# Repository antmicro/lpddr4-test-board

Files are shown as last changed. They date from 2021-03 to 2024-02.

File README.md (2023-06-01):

# LPDDR4 test board

Copyright (c) 2021-2023 [Antmicro](https://antmicro.com)



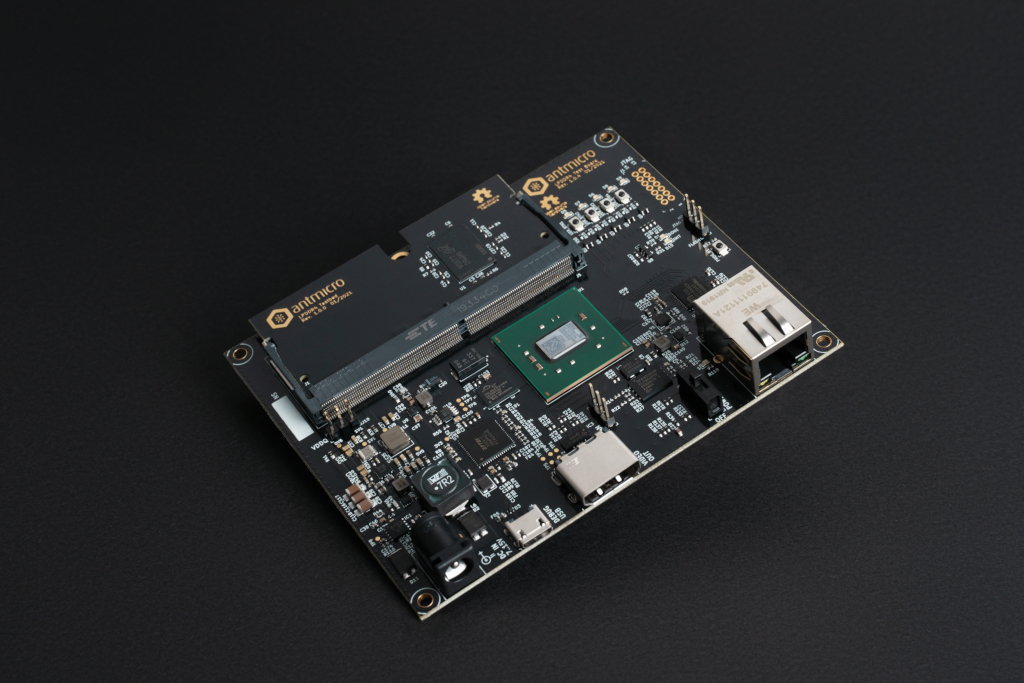
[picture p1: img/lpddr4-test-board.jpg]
LPDDR4 test board


## Overview

This repository contains open hardware design files for an experimental platform built around Xilinx Kintex-7 FPGA.
The main purpose of this platform is to develop and customize RAM controllers supporting LPDDR4 ICs.

This hardware platform is supported by the [Rowhammer Tester](https://github.com/antmicro/rowhammer-tester) gateware.
It can be used to investigate Rowhammer DRAM attacks.
You can learn more about Rowhammer attacks from this blog [note](https://antmicro.com/blog/2021/08/open-source-ddr-test-framework-for-rowhammer/).
The usage instructions for this board are also provided in the [Row Hammer Tester documentation](https://rowhammer-tester.readthedocs.io/en/latest/).

The design files for this board were prepared in KiCad.

## Repository structure

The main repository directory contains KiCad PCB project files, a LICENSE and README.
The remaining files are stored in the following directories:

* `lib` - contains the component libraries
* `img` - contains graphics for this README

## Key features

* Kintex-7 FPGA - XC7K70T-FBG484
* Modular design with custom DDR4 SO-DIMM connector for various testbeds
* HDMI output connector
* Ethernet RJ45 connector with 1GbE transceiver
* Micro USB debug connector with FT4232HQ FTDI USB controller
* JTAG
* microSD card slot
* 16Mbytes S25FL128S QSPI FLASH memory
* S27KL0641 HyperRAM
* External 7-12V power input
* 5 user LEDs
* 4 user buttons

The LPDDR4 test board is electrically compatible with the following testbeds:

* [LPDDR4 Testbed](https://github.com/antmicro/lpddr4-testbed) with a single LPDDR4 IC
* [DDR5 Testbed](https://github.com/antmicro/ddr5-testbed) with a signle DDR5 IC

## Block diagram

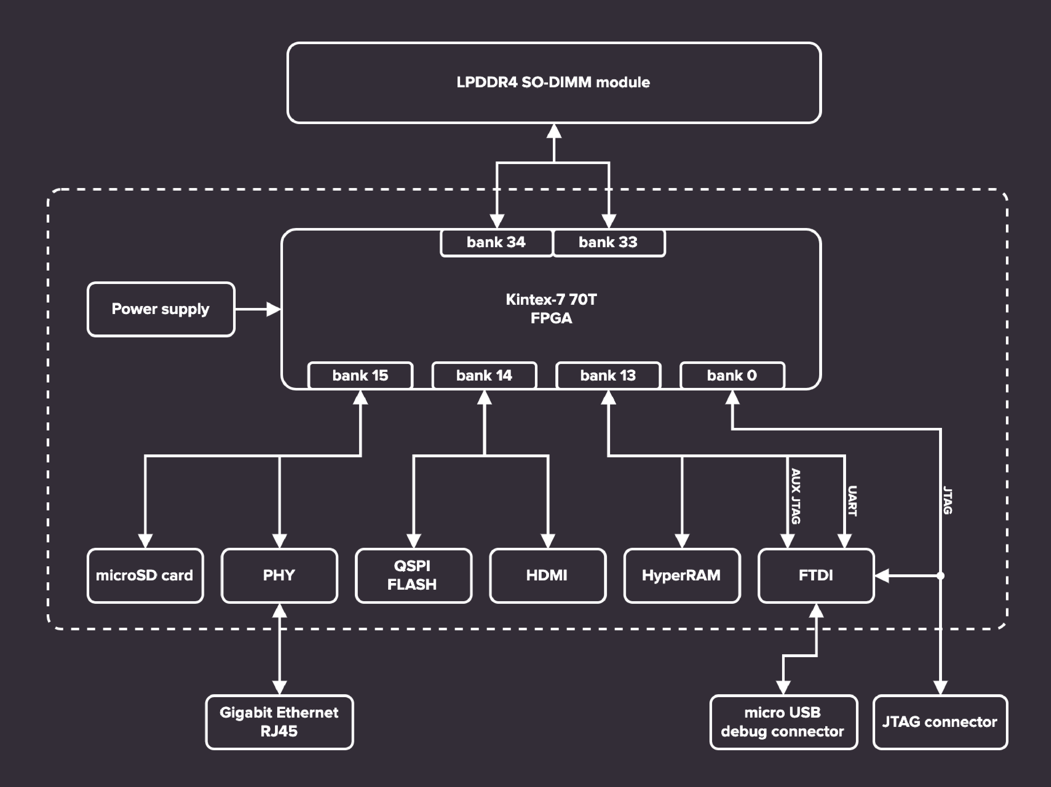
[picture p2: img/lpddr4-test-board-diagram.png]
Block diagram


## Licensing

This project is published under the [Apache-2.0](LICENSE) license.

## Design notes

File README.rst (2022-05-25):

=================
LPDDR4 test board
=================

Copyright (c) 2020-2022 `Antmicro <https://www.antmicro.com>`_





Overview
--------

This repository contains open hardware design files for an experimental platform built around Xilinx Kintex-7 FPGA.
The main purpose of this platform is to develop and customize RAM controllers supporting LPDDR4 ICs.

This hardware platform is supported by the `LiteX Rowhammer Tester <https://github.com/antmicro/litex-rowhammer-tester>`_ gateware. It can be used to investigate Rowhammer DRAM attacks. You can learn more about Rowhammer attacks from this blog `note <https://antmicro.com/blog/2021/08/open-source-ddr-test-framework-for-rowhammer/>`_.
The usage instructions for this board are also provided in the `LiteX Row Hammer Tester documentation <https://litex-rowhammer-tester.readthedocs.io/en/latest/>`_. 

The design files for this board were prepared in KiCad.

Repository structure
--------------------
The main repository directory contains KiCad PCB project files, a LICENSE and README.
The remaining files are stored in the following directories:

* ``lib`` - contains the component libraries
* ``img`` - contains graphics for this README

Key features
------------

* Kintex-7 FPGA - XC7K70T-FBG484
* Modular design with custom DDR4 SO-DIMM connector
* HDMI output connector
* Ethernet RJ45 connector with 1GbE transceiver
* Micro USB debug connector with FT4232HQ FTDI USB controller
* JTAG
* microSD card slot
* 16Mbytes S25FL128S QSPI FLASH memory
* S27KL0641 HyperRAM
* External 7-12V power input
* 5 user LEDs
* 4 user buttons

Block diagram
-------------


	
License
=======

`Apache-2.0 <LICENSE>`_

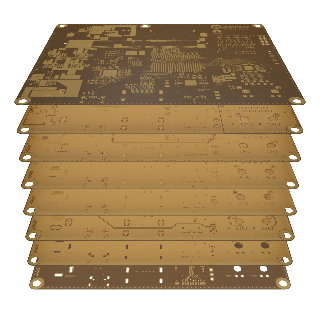
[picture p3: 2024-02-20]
assets/previews/layer1_thumbnail.webp

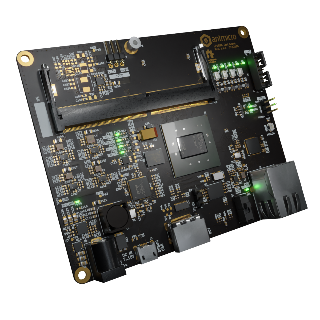
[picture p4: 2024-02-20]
assets/previews/leftT_thumbnail.png

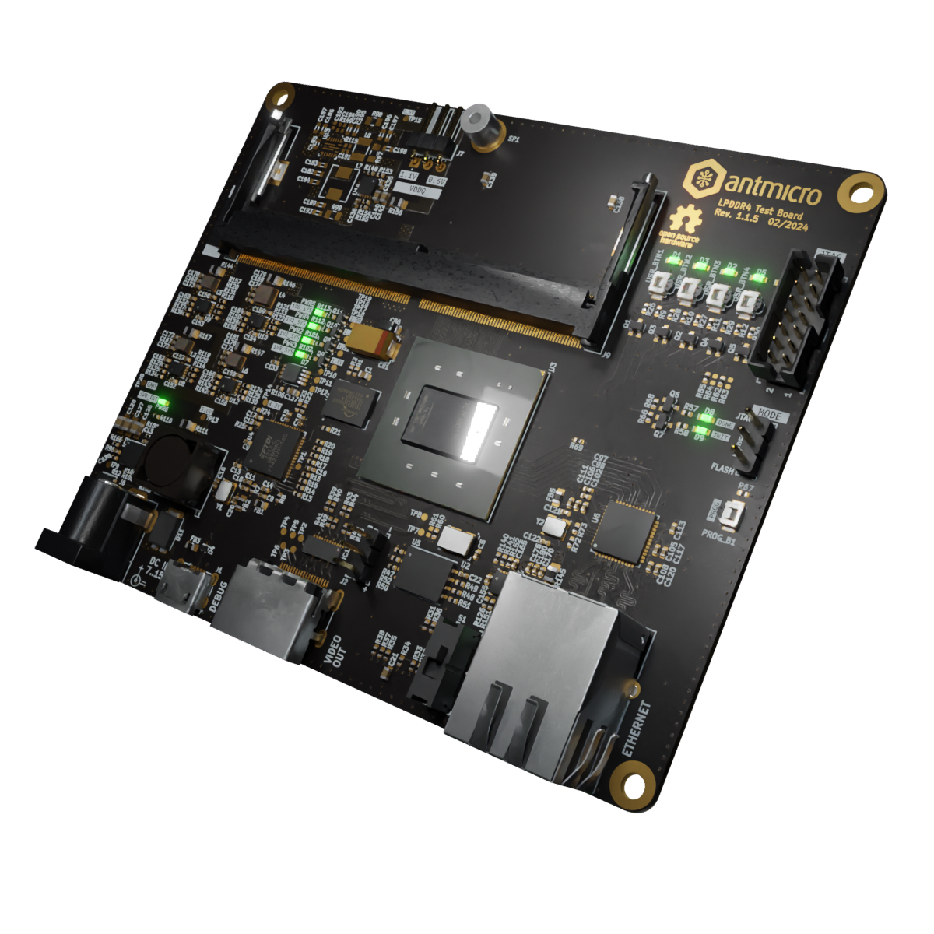
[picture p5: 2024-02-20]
assets/previews/rightT.webp

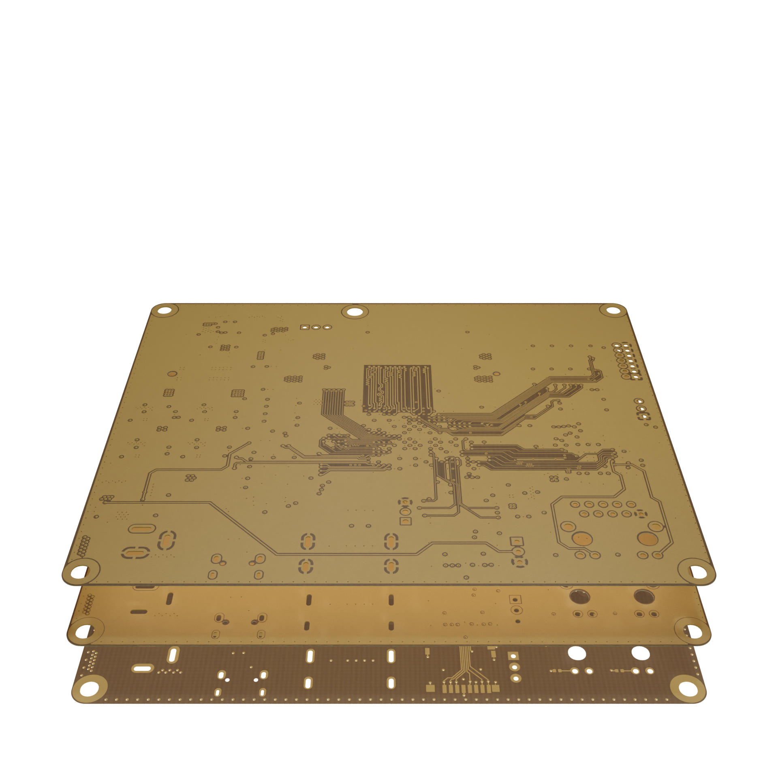
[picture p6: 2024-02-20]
assets/previews/layer6.png

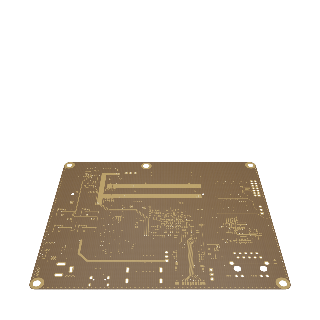
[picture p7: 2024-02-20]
assets/previews/layer8_thumbnail.png

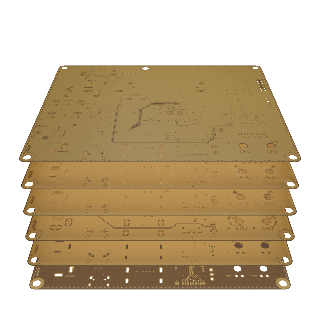
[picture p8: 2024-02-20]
assets/previews/layer3_thumbnail.webp

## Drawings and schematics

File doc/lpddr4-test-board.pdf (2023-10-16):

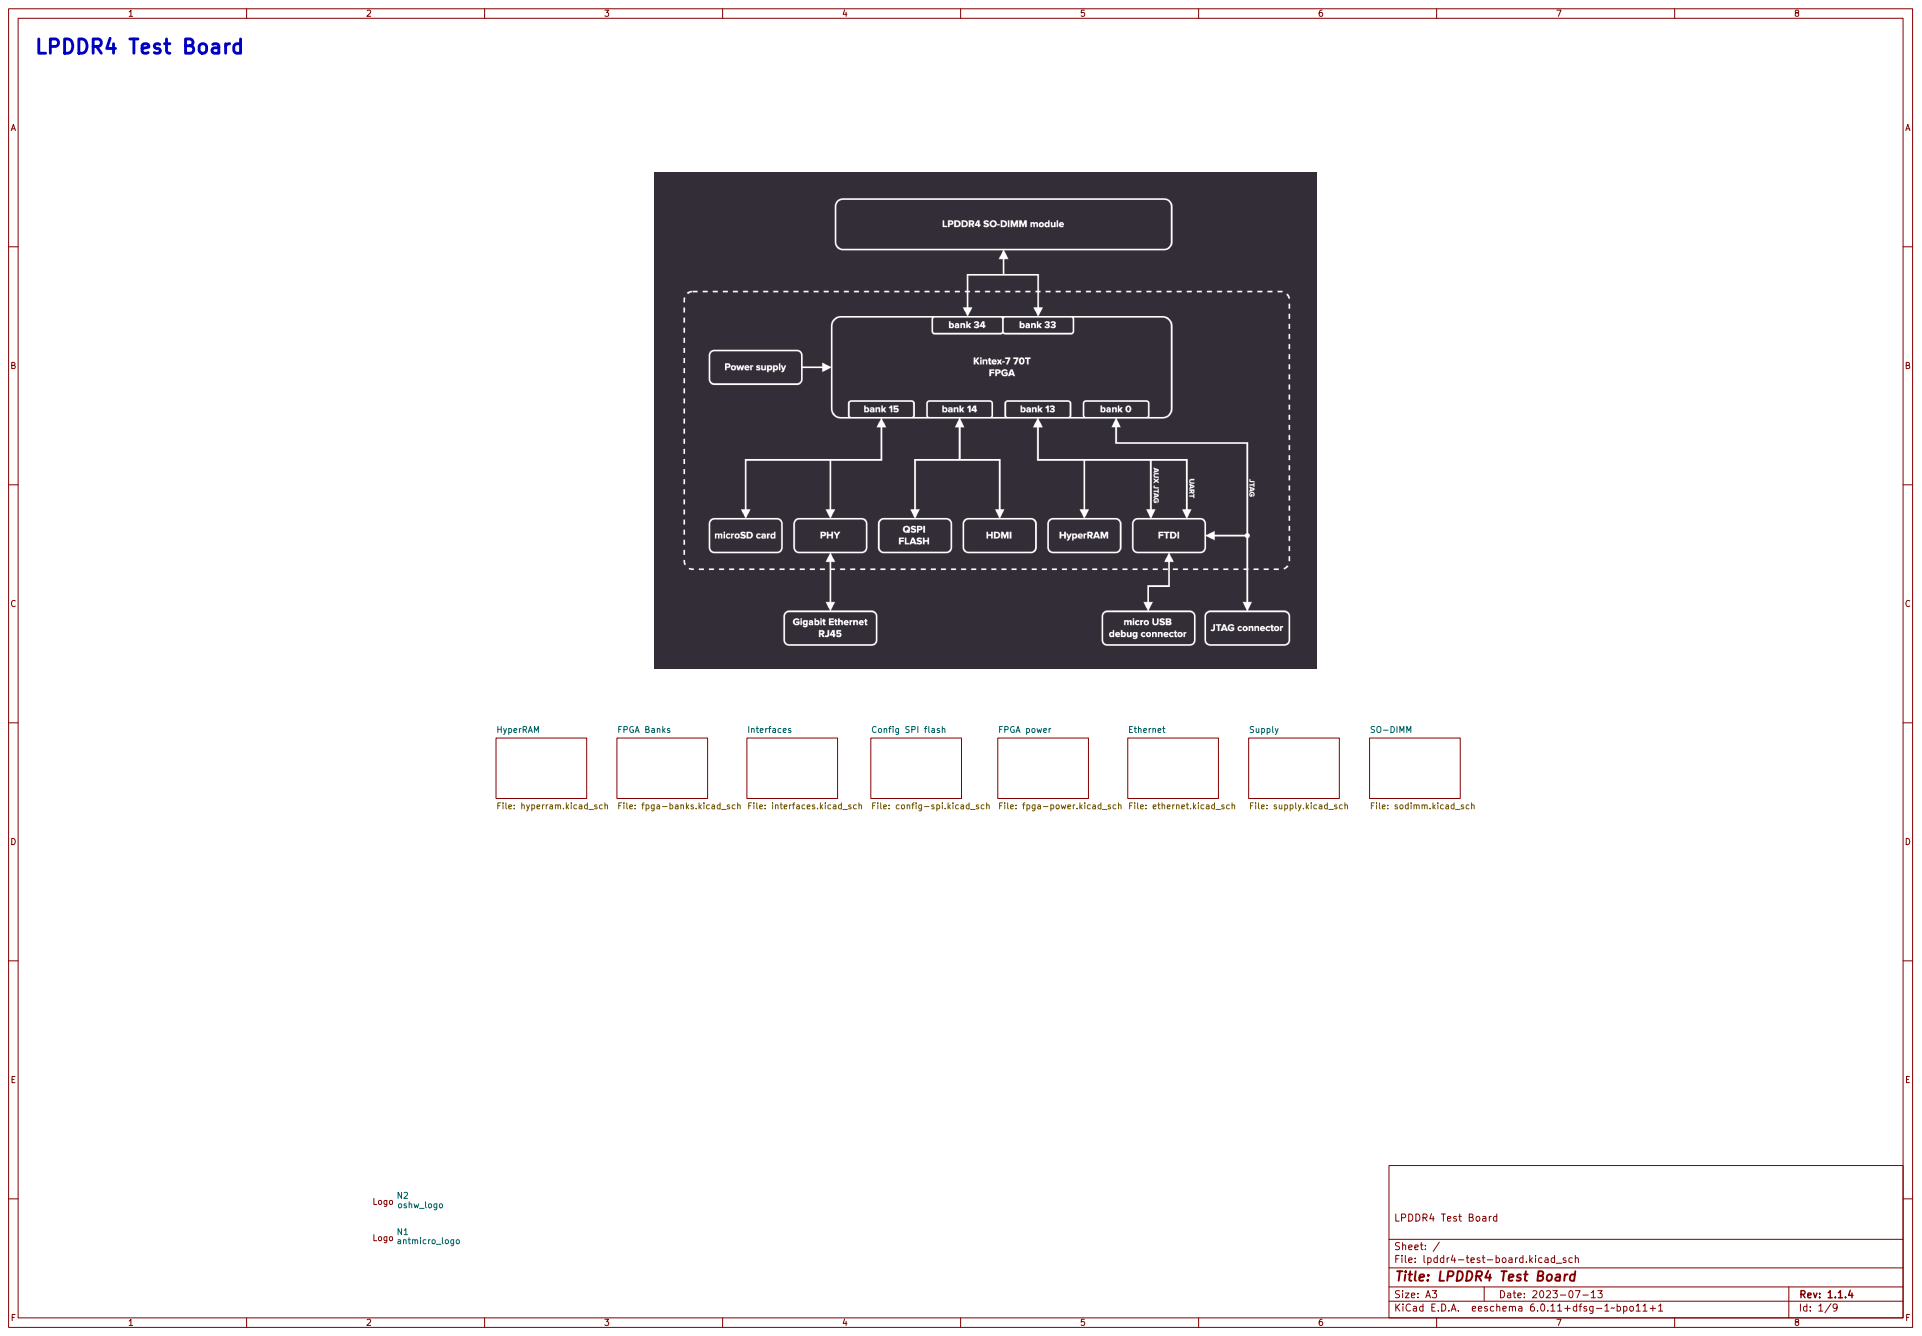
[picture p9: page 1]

Interfaces File: interfaces.kicad_sch HyperRAM

Supply File: supply.kicad_sch FPGA Banks File: fpga-banks.kicad_sch

Config SPI flash File: config-spi.kicad_sch

File: sodimm.kicad_sch FPGA power File: fpga-power.kicad_sch

File: lpddr4-test-board.kicad_sch Sheet: / LPDDR4 Test Board

Id: 1/9 Title: LPDDR4 Test Board

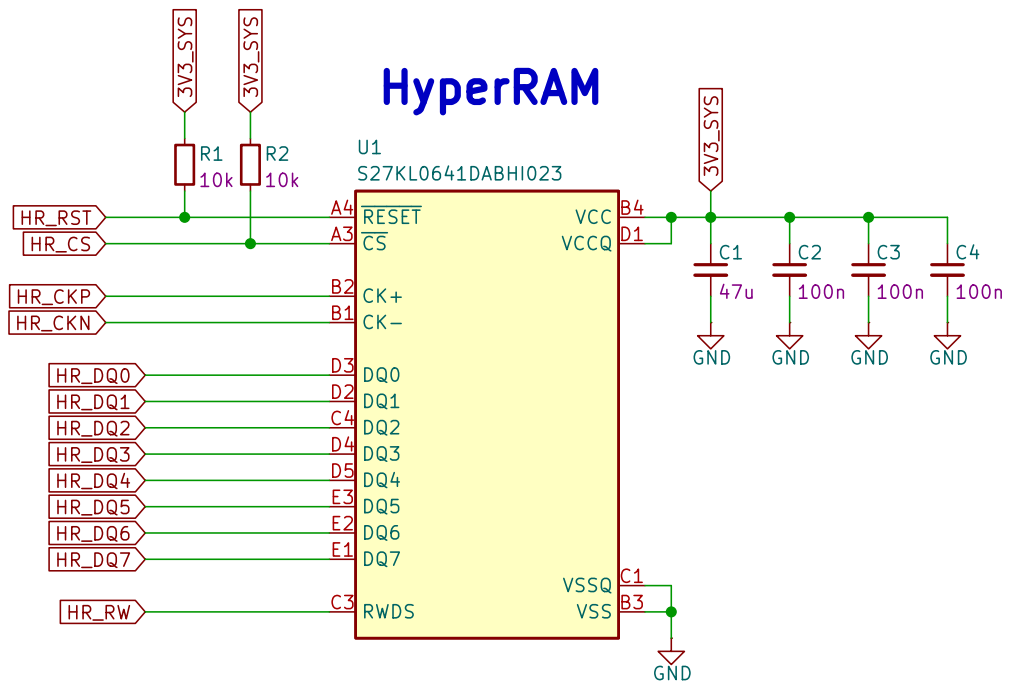
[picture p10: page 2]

Id: 2/9 Title: LPDDR4 Test Board

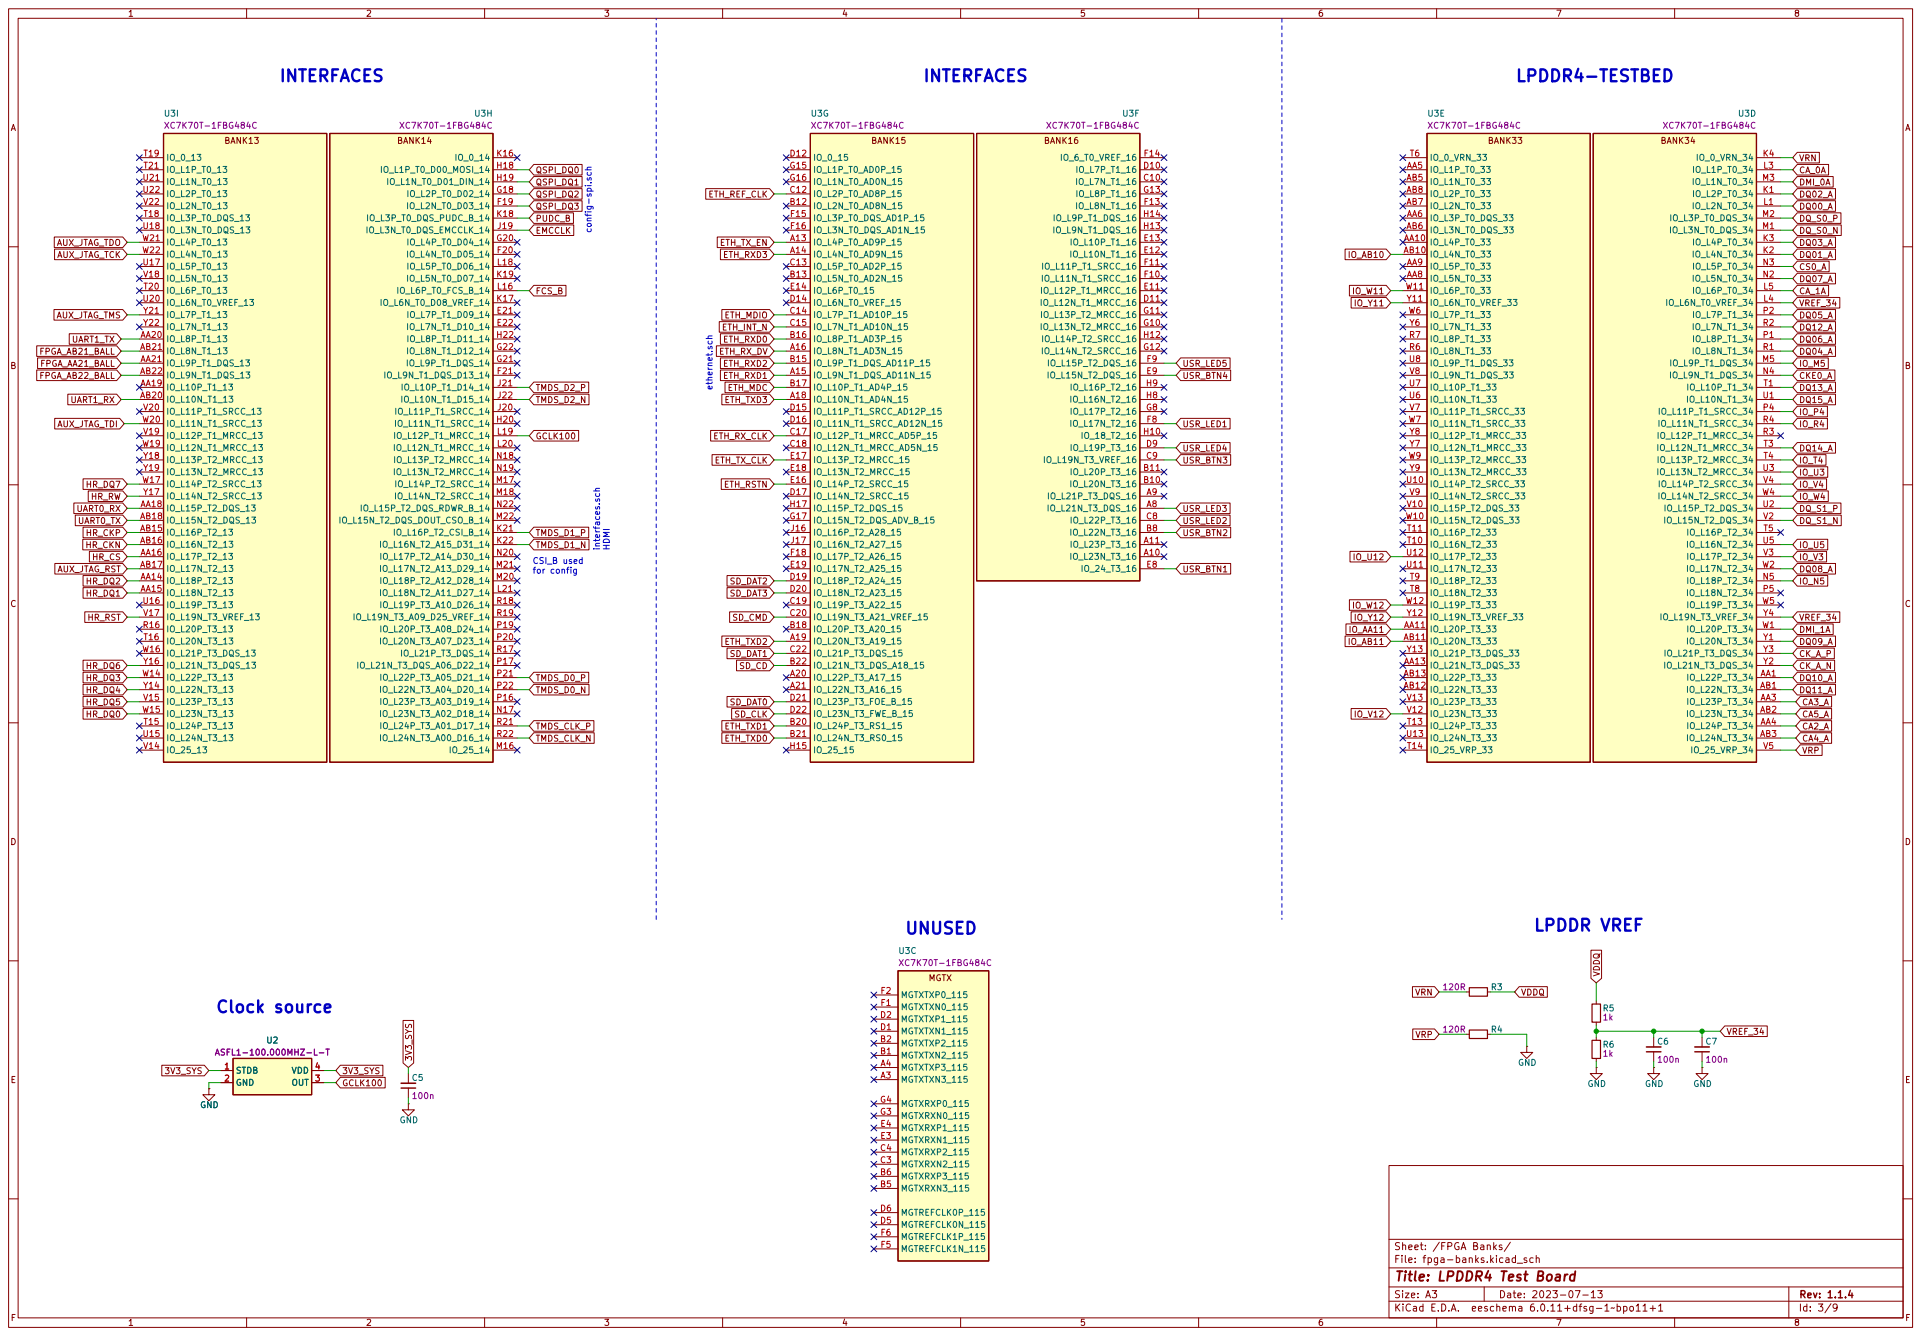
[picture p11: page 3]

File: fpga-banks.kicad_sch Sheet: /FPGA Banks/ GND

Id: 3/9 Title: LPDDR4 Test Board

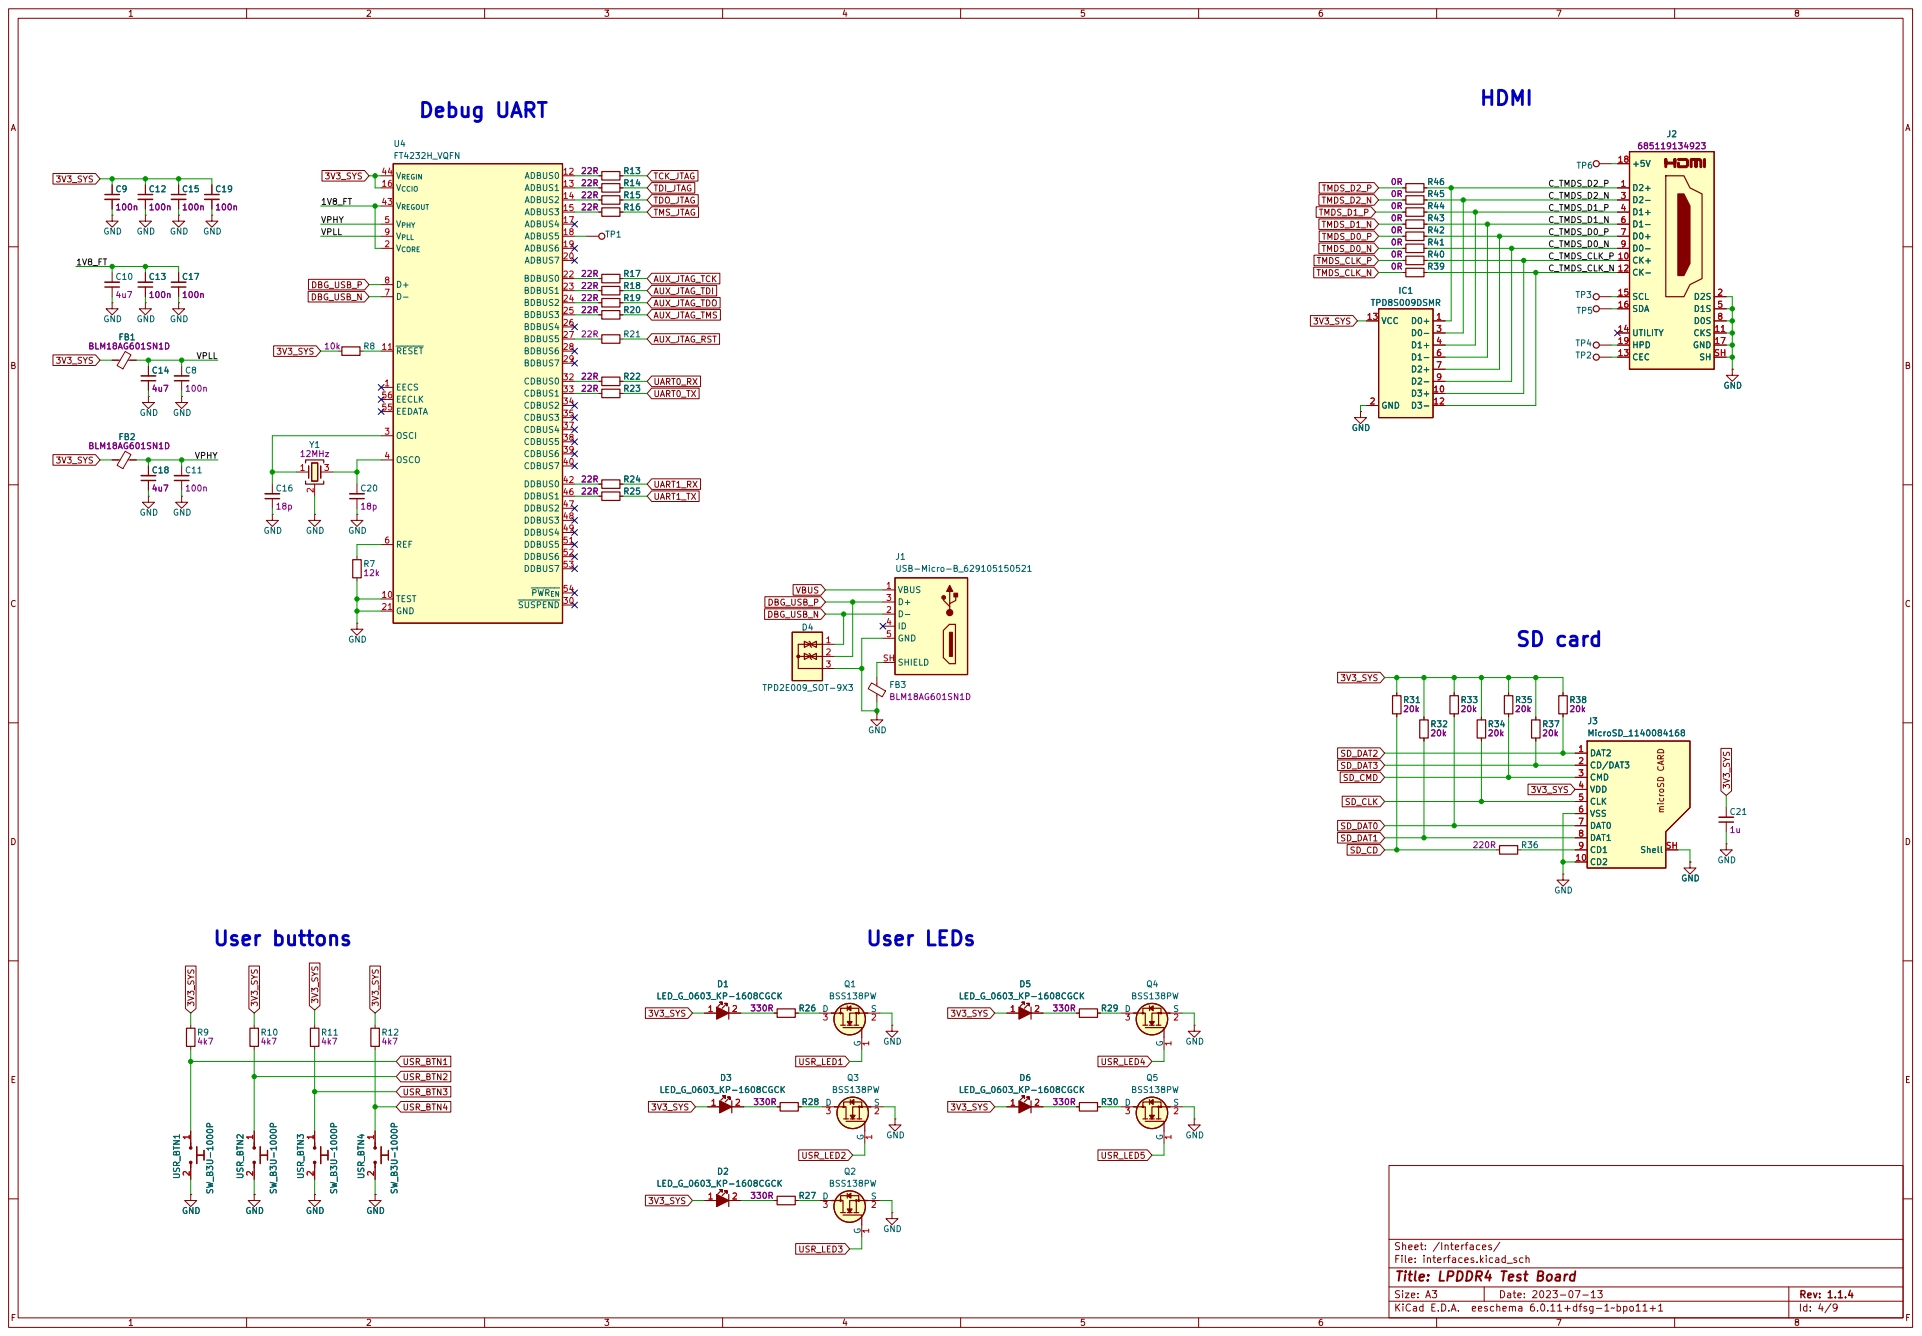
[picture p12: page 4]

File: interfaces.kicad_sch Sheet: /Interfaces/
Id: 4/9 Title: LPDDR4 Test Board

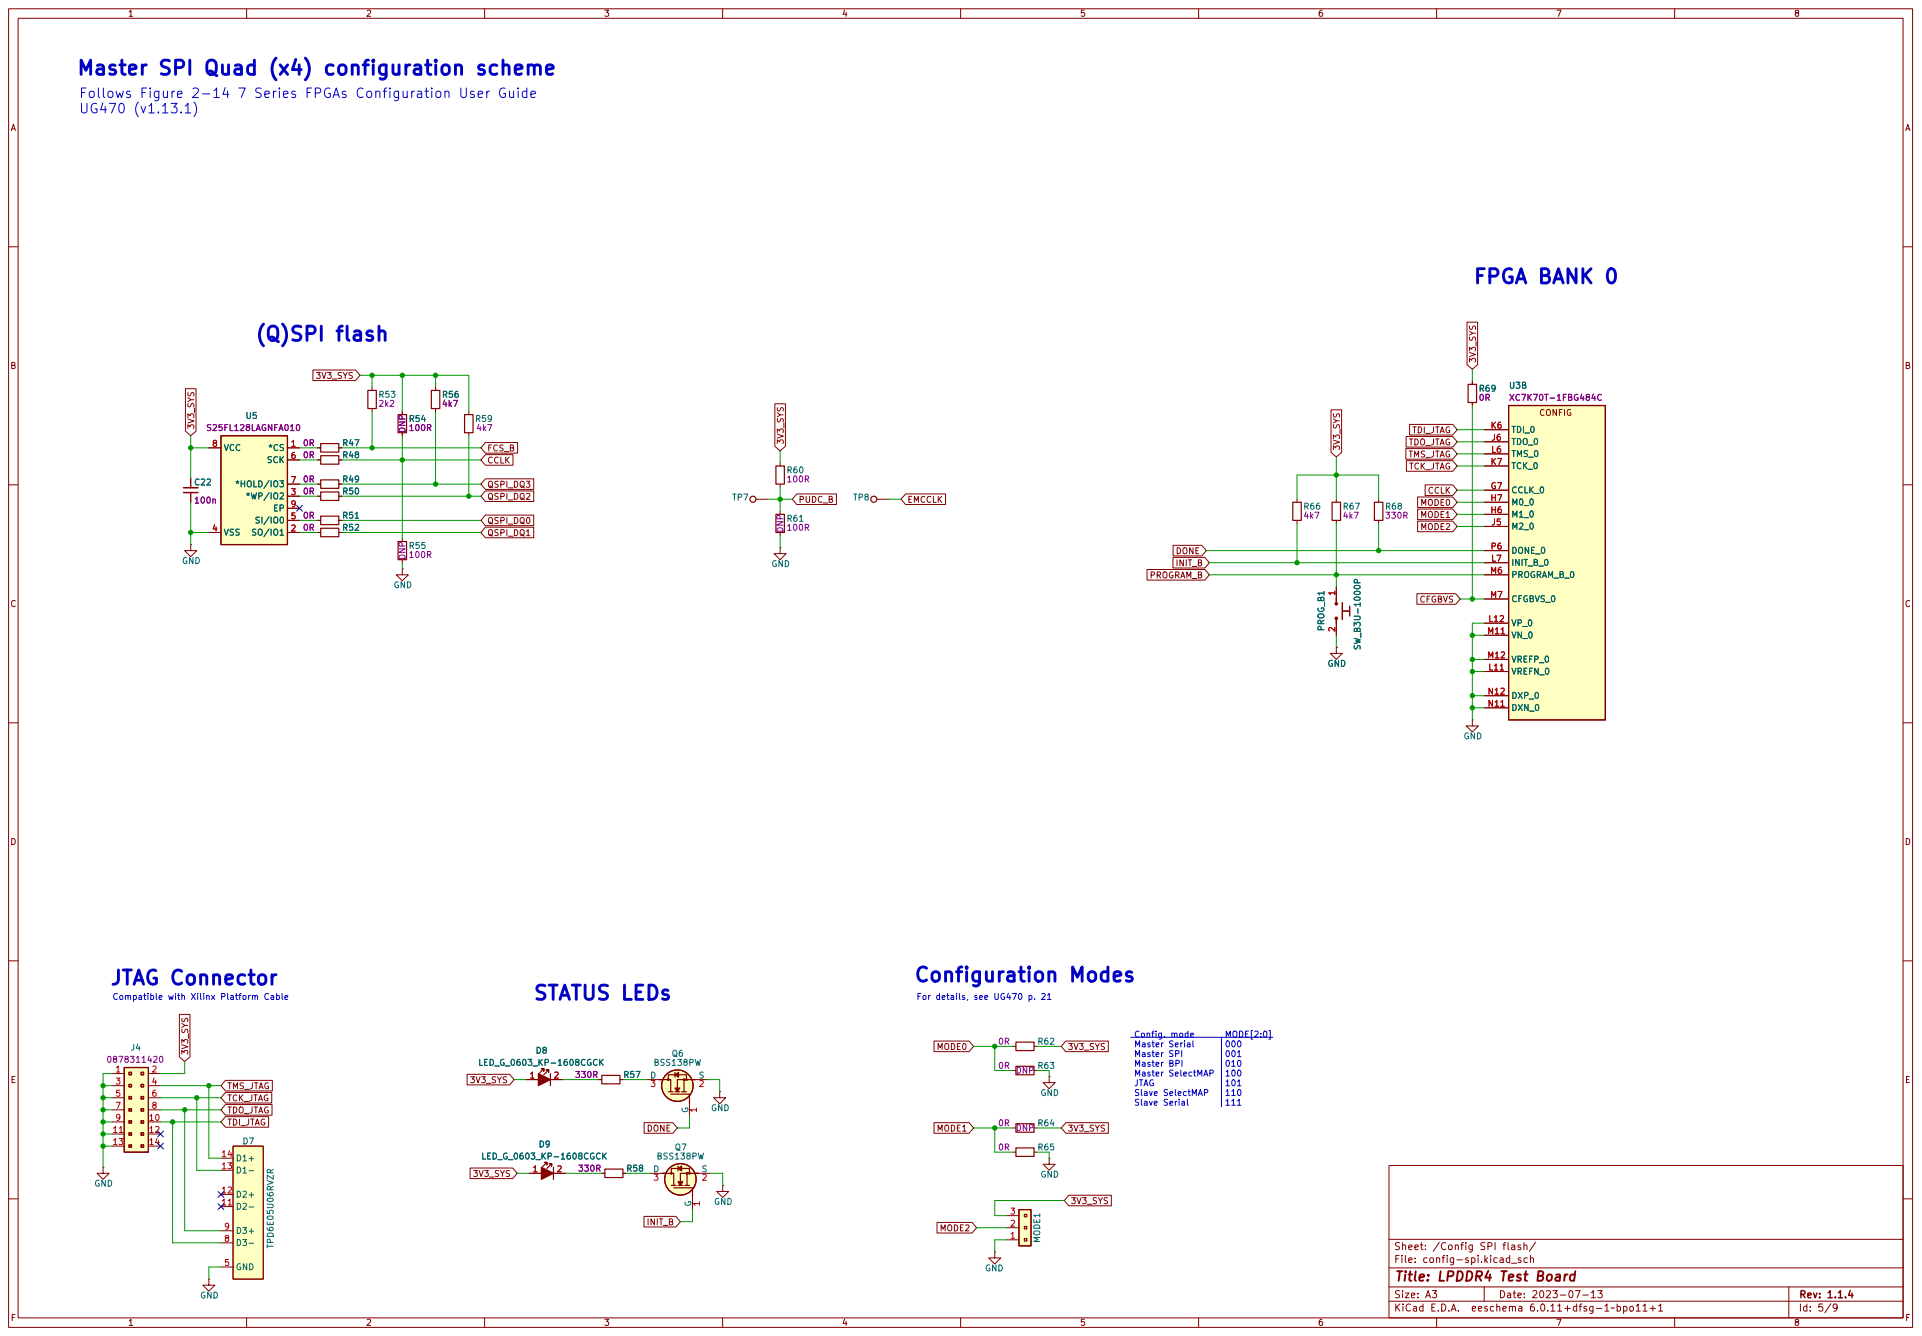
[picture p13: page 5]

9 | 10

Id: 5/9 Title: LPDDR4 Test Board

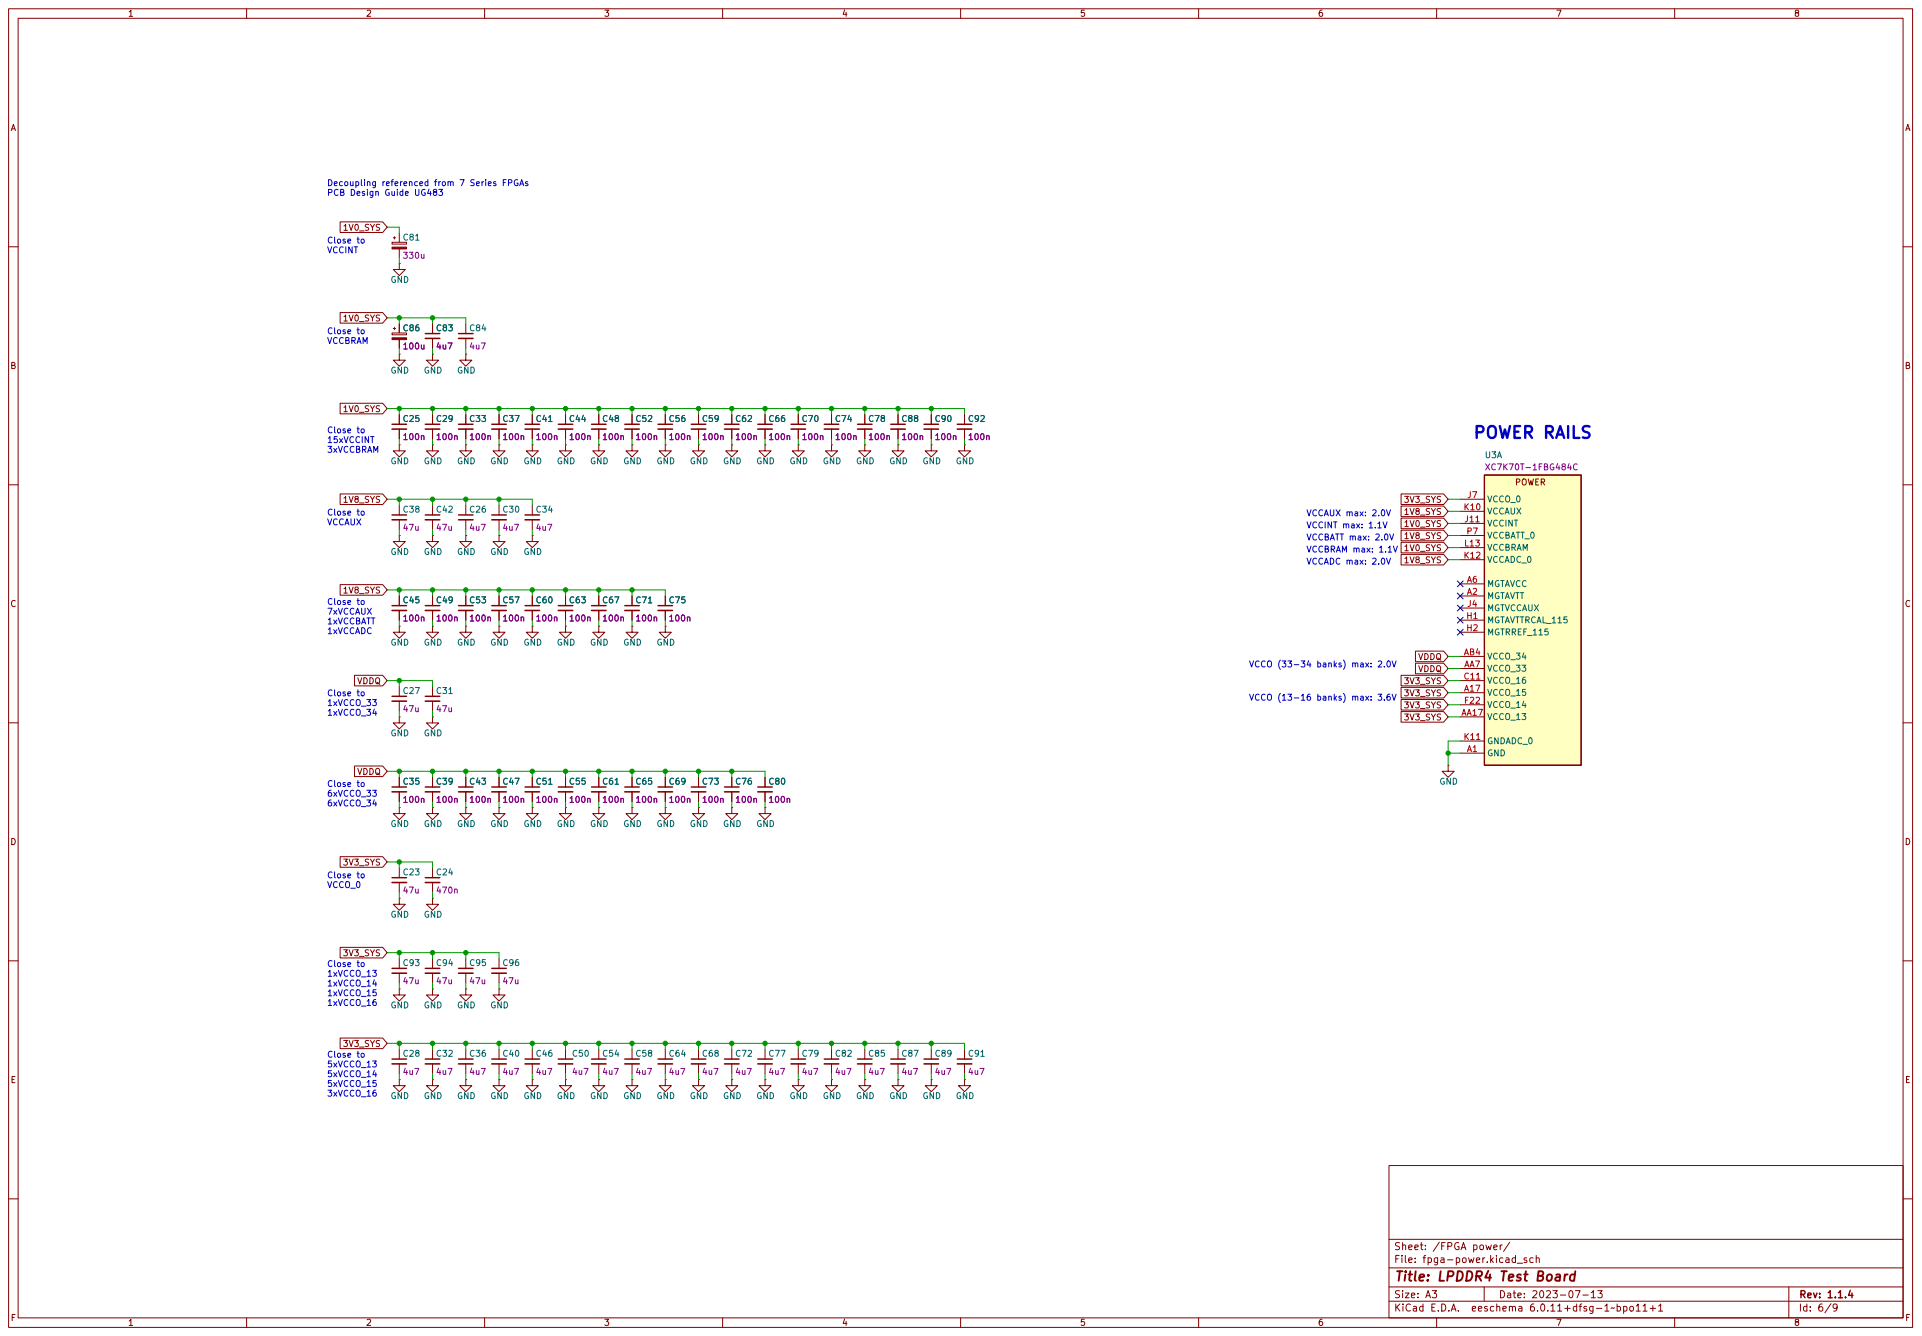
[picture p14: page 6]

VCCBATT max: 2.0V Close to

Id: 6/9 Title: LPDDR4 Test Board

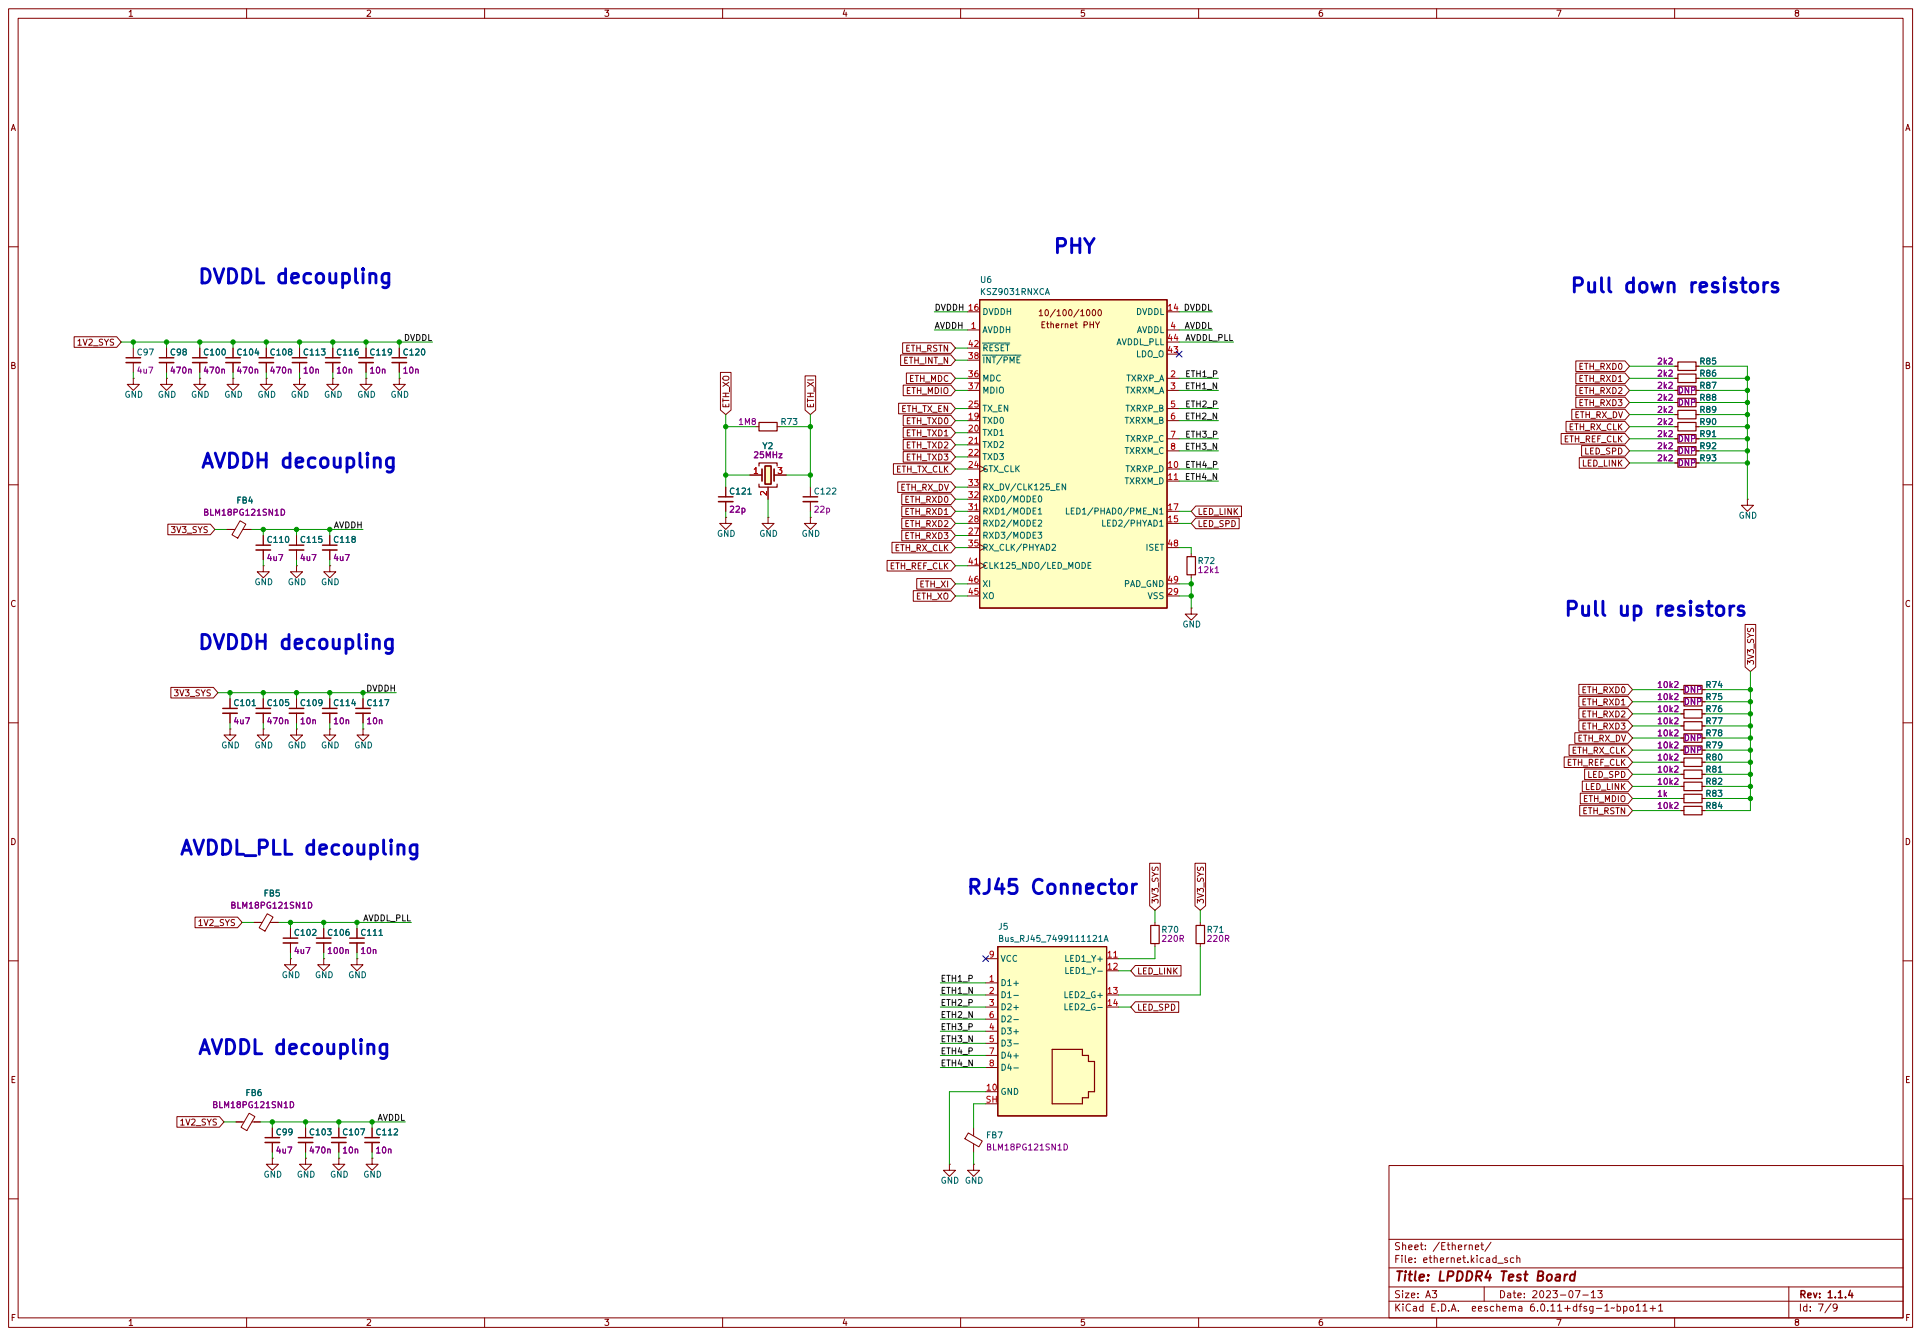
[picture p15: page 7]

File: ethernet.kicad_sch Sheet: /Ethernet/
Id: 7/9 Title: LPDDR4 Test Board

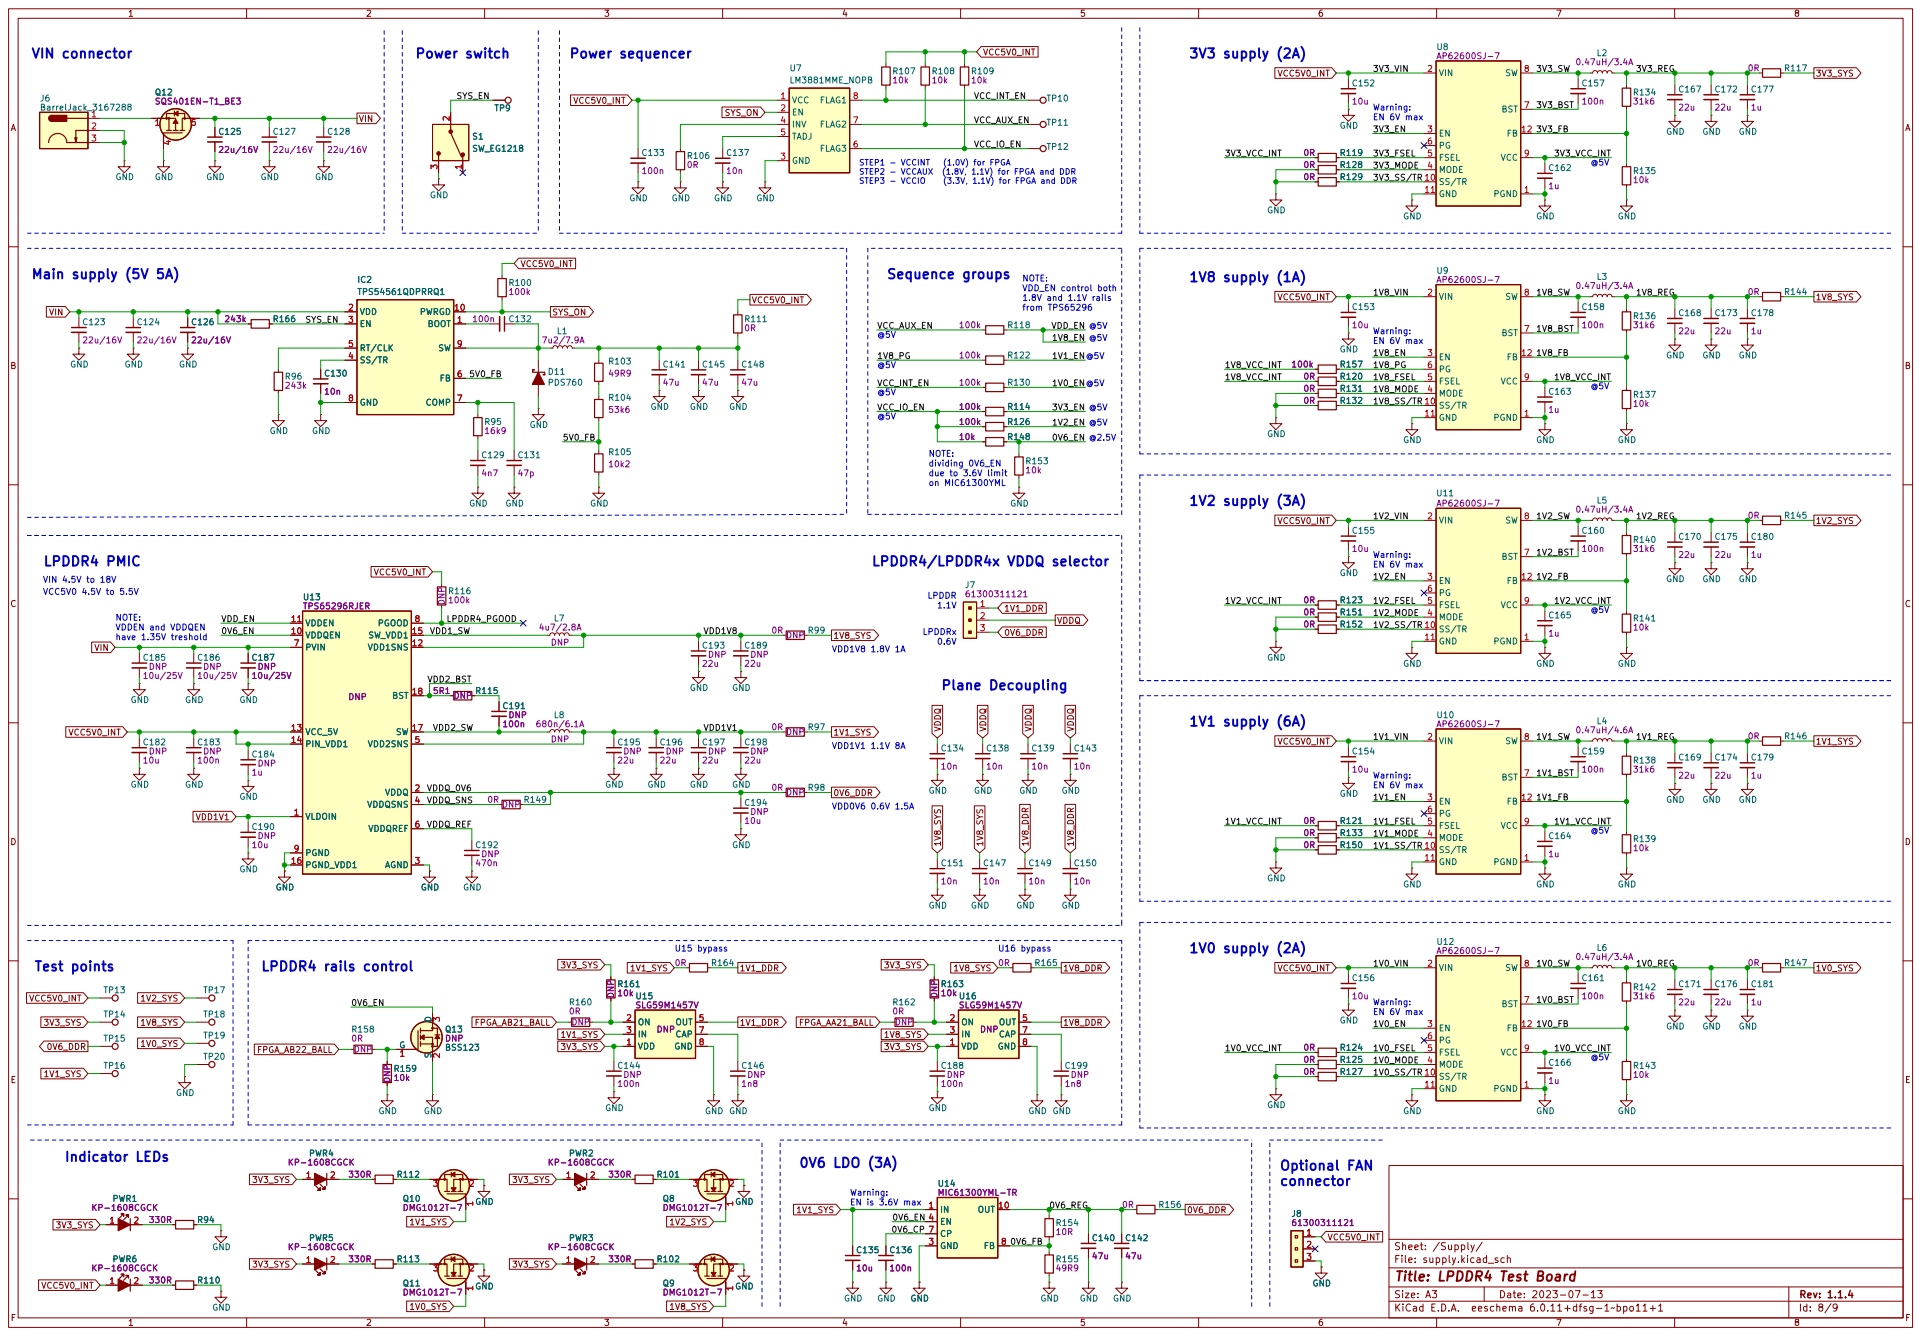
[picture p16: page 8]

STEP2 - VCCAUX (1.8V, 1.1V) for FPGA and DDR

have 1.35V treshold VIN 4.5V to 18V LPDDR4 PMIC

VCC5V0 4.5V to 5.5V NOTE: VDDEN and VDDQEN

Warning: EN is 3.6V max

File: supply.kicad_sch Sheet: /Supply/
Id: 8/9 Title: LPDDR4 Test Board

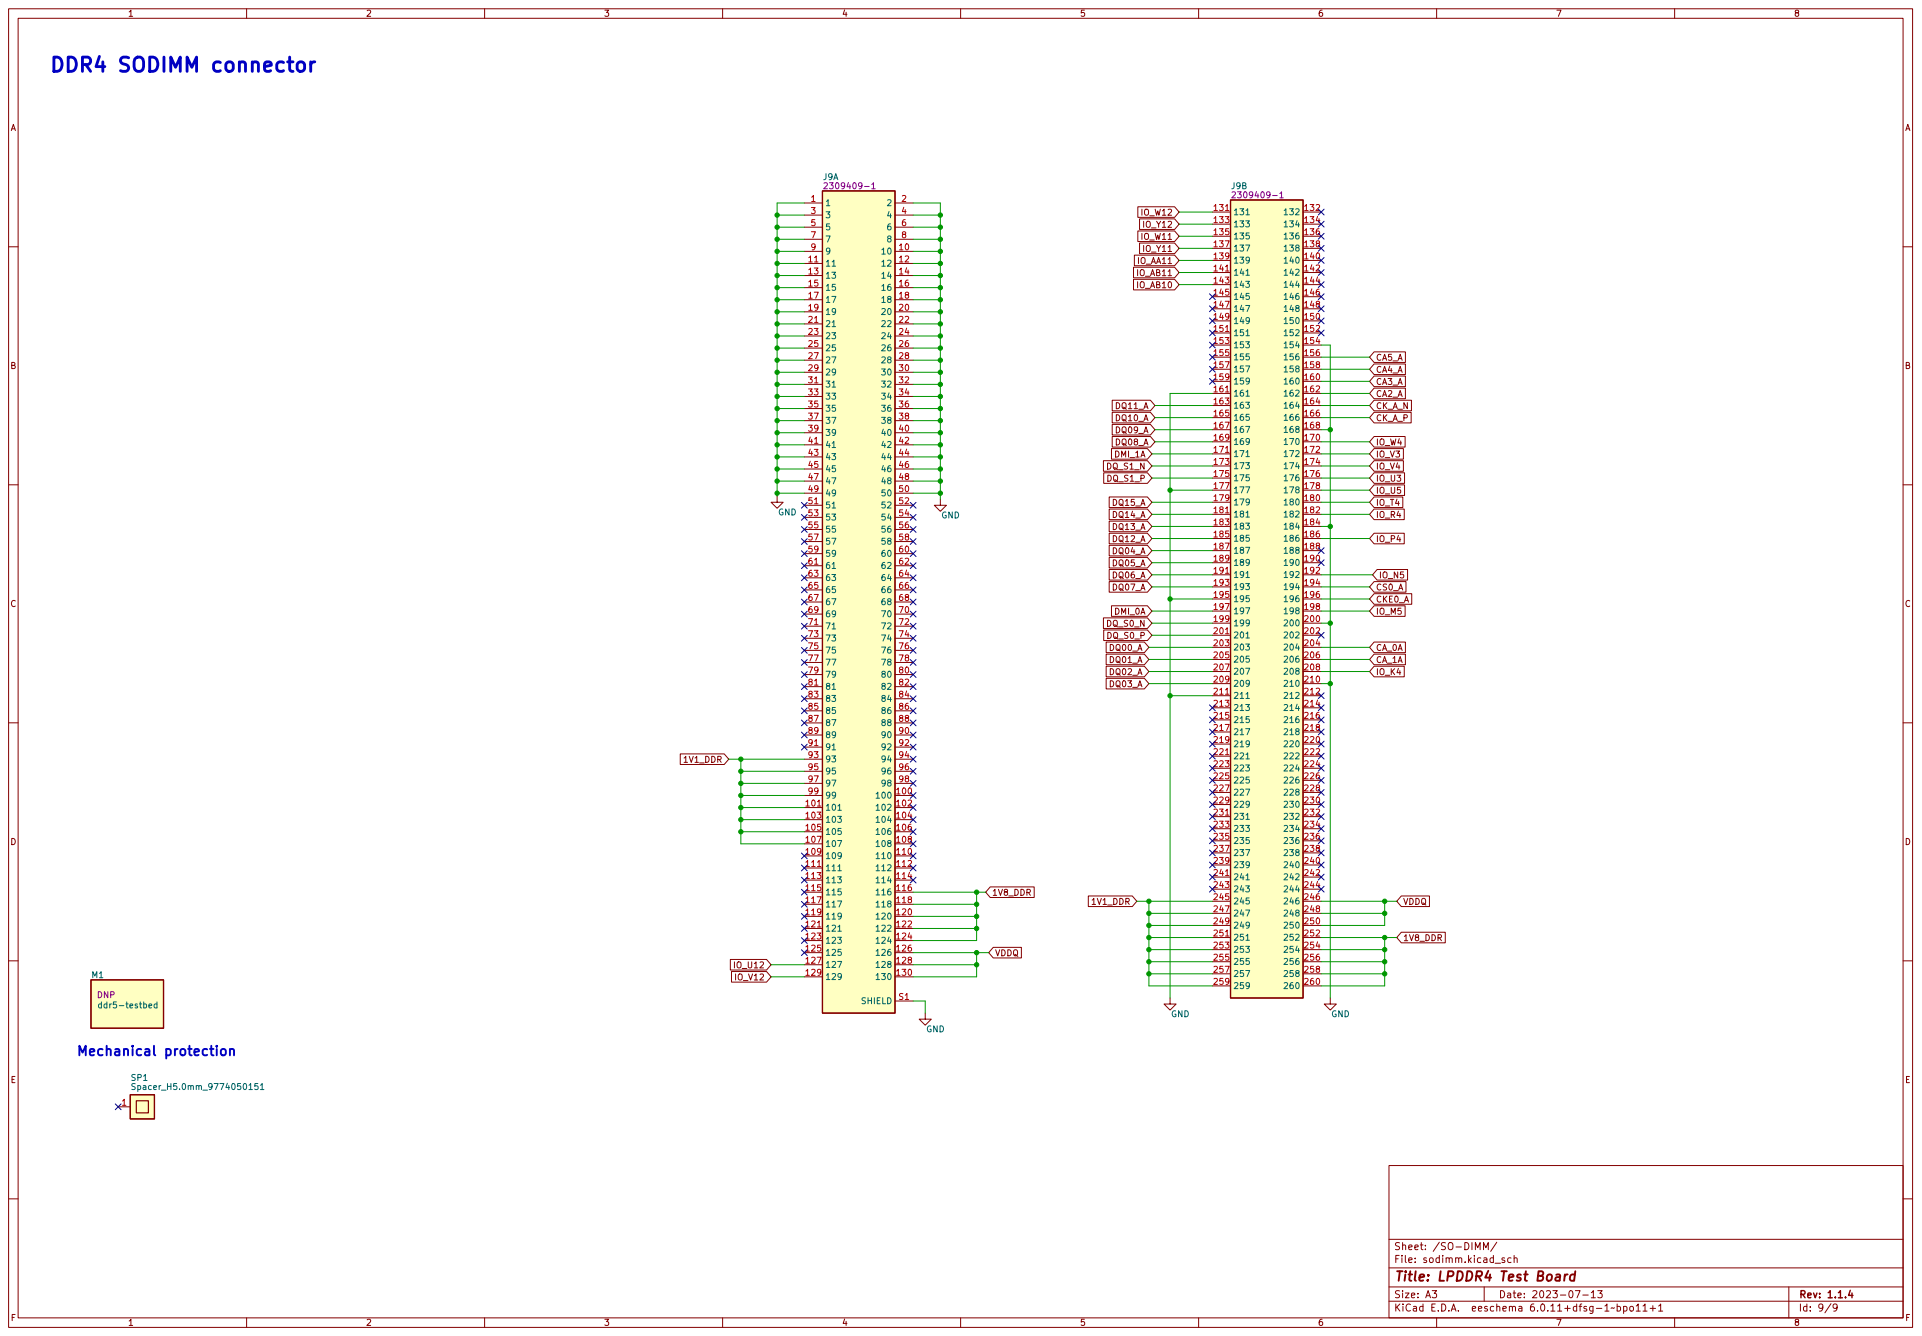
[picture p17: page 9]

29 11 | 3 3 | 12
49 | 5 5 | 20

13 | | 14
15 | | 16
17 | | 18

21 | | 22
23 | | 24
25 | | 26

31 | 32
33 | 34

File: sodimm.kicad_sch Sheet: /SO-DIMM/
Id: 9/9 Title: LPDDR4 Test Board

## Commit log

2020-11-19 Add Design files after internal cleanup
    [config-spi.sch, ethernet.sch, fpga-banks.sch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]
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2020-11-19 Add title block to the schematic sheets and some TODOs
    [config-spi.sch, ethernet.sch, fpga-banks.sch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]
2020-11-19 Connect proper voltage to FPGA banks
    [fpga-banks.sch]
2020-11-19 Coponent placement - WIP
    [lpddr4-test-board.kicad_pcb]
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2020-11-19 Add Xilinx Platfom Cable JTAG interface
    [config-spi.sch]
2020-11-19 Add debug configuration resistors
    [config-spi.sch]
2020-11-19 Update supply related circuits
    [fpga-banks.sch, fpga-power.sch, sodimm.sch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]
2020-11-19 Replace SO-DIMM DDR4 to SO-DIMM DDR3 connector
    [sodimm.sch]
2020-11-19 Replace DDR4 on PCB and rearrange interfaces
    [lpddr4-test-board.kicad_pcb]
2020-11-20 Add routing between FPGA and SO-DIMM WIP
    [fpga-banks.sch, lpddr4-test-board.kicad_pcb, sodimm.sch]
2020-11-23 Rebuild connections to fit lpddr4 module (WIP)
    [fpga-banks.sch, lpddr4-test-board.kicad_pcb, sodimm.sch]
2020-11-23 Add SD card routing
    [lpddr4-test-board.kicad_pcb]
2020-11-25 Add LPDDR4 routing and equalize traces - WIP
    [fpga-banks.sch, lpddr4-test-board.kicad_pcb, sodimm.sch]
2020-11-25 Add LPDDR4 routing with equalized traces - WIP
    [fpga-banks.sch, lpddr4-test-board.kicad_pcb, sodimm.sch]
2020-11-26 Add ethernet routing - WIP
    [lpddr4-test-board.kicad_pcb]
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2020-11-26 Library cleanup, add RGMII layout
    [config-spi.sch, ethernet.sch, fpga-banks.sch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]
2020-11-26 Instantiate unused FPGA blocks
    [fpga-banks.sch, fpga-power.sch, lpddr4-test-board.kicad_pcb]
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2020-11-26 Move JTAG connector to the right, add layout
    [config-spi.sch, fpga-banks.sch, lpddr4-test-board.kicad_pcb]
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2020-11-26 Move SD to B15
    [fpga-banks.sch, lpddr4-test-board.kicad_pcb]
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2020-11-26 Update SPI configuration setup
    [config-spi.sch, fpga-banks.sch]
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2020-11-27 Add power supply routing
    [lpddr4-test-board.kicad_pcb, sodimm.sch, supply.sch]
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2020-11-28 re-assinged DDR4 Channel A DQ and CA lanes
    [fpga-banks.sch, lpddr4-test-board.kicad_pcb, sodimm.sch]
2020-11-28 Add User buttons to schematic
    [fpga-banks.sch, interfaces.sch]
2020-11-28 Route user buttons to FPGA
    [lpddr4-test-board.kicad_pcb]
2020-11-28 Add voltage level selector
    [sodimm.sch, supply.sch]
2020-11-28 Add vlotage slection jumper to PCB
    [lpddr4-test-board.kicad_pcb]
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2020-11-28 Update changes to PCB
    [lpddr4-test-board.kicad_pcb]
2020-11-29 Connect CA and spare IOs to SODIMM
    [fpga-banks.sch, lpddr4-test-board.kicad_pcb, sodimm.sch]
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2020-11-29 Remove VBUS overcurrent protector
    [lpddr4-test-board.kicad_pcb, supply.sch]
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2020-11-30 Update buttons and LEDs connection
    [fpga-banks.sch, interfaces.sch]
2020-11-30 Move buttons under LEDs
    [lpddr4-test-board.kicad_pcb]
2020-11-30 Add power planes - WIP
    [lpddr4-test-board.kicad_pcb]
2020-11-30 Replace 5R1 resistor and clean up
    [supply.sch]
2020-11-30 Place and route new 5R1 resistor
    [lpddr4-test-board.kicad_pcb]
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2020-11-30 Place and route decoupling capacitors
    [fpga-power.sch, lpddr4-test-board.kicad_pcb]
2020-11-30 Update caps around ADC
    [fpga-banks.sch]
2020-11-30 Remove unused ADC channels
    [fpga-banks.sch]
2020-11-30 Add FPGA - FTDI JTAG connections
    [lpddr4-test-board.kicad_pcb]
2020-11-30 Rotate U7 for better signal alignment
    [lpddr4-test-board.kicad_pcb]
2020-11-30 Connect power supply to SO-DIMM connector
    [sodimm.sch]
2020-11-30 Add aux JTAG connection to schematics
    [interfaces.sch, lpddr4-test-board.kicad_pcb]
2020-11-30 Remove redundant signals from the SODIMM
    [sodimm.sch]
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2020-11-30 Fix VCC labels
    [config-spi.sch]
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2020-11-30 Fix labels
    [interfaces.sch]
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2020-12-01 Replace VCC3V3 with 3V3_SYS
    [config-spi.sch, ethernet.sch, fpga-banks.sch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]
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2020-12-09 Add TODO related to Bank 13 signal assignment
    [fpga-banks.sch]
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2020-12-09 Reconnect AUX_JTAG + UART, Connect spare IOs to the SODIMM
    [fpga-banks.sch, lpddr4-test-board.kicad_pcb, sodimm.sch]
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2020-12-10 Minor fixes
    [supply.sch]
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2020-12-10 SWAP DQ_07A with DMI_0A
    [fpga-banks.sch, lpddr4-test-board.kicad_pcb, sodimm.sch]
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2021-01-12 Reconnect GCLK100 -> L19 ETH_TX_CLK -> E17 ETH_RX_CLK -> C17
    [fpga-banks.sch, lpddr4-test-board.kicad_pcb]
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2021-01-13 Add voltage divider for B34 VREF to make it VDDQ/2
    [fpga-banks.sch, lpddr4-test-board.kicad_pcb]
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2021-01-14 Move logotypes to the right top corner. Update designators and layout
    [fpga-power.sch]
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2021-01-15 Bump release to 1.0.4, Tweak the TMDS impedance
    [config-spi.sch, ethernet.sch, fpga-banks.sch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]
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2021-03-08 Fix broken labels
    [ethernet.sch, supply.sch]
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2021-03-08 Add pull up resistors to power supply sequencer signals
    [supply.sch]
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2022-07-05 Migrate project to KiCad6, change DCDCs to AP62301WU-7
    [config-spi.kicad_sch, config-spi.sch, ethernet.kicad_sch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]
2022-07-05 Fix 1V1 connected to GND
    [sodimm.kicad_sch]
2022-07-05 Fix broken test-points
    [config-spi.kicad_sch, interfaces.kicad_sch]
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2022-07-05 Update broken symbols definitions
    [lpddr4-test-board.kicad_sch]
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2022-07-06 Replace FT2232H-56Q with FT4232H-56Q
    [interfaces.kicad_sch]
2022-07-06 Fix annotation, improve readability
    [supply.kicad_sch]
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2022-07-06 Fix issues after returning from local branch
    [fpga-banks.kicad_sch, lpddr4-test-board.kicad_sch]
2022-07-07 Placement and routing of FT4232H. Re annotation of the schematics
    [config-spi.kicad_sch, ethernet.kicad_sch, fpga-banks.kicad_sch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]
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2022-07-07 Add 3d model of DDR5 testbed. Fix annotation
    [ethernet.kicad_sch, fpga-power.kicad_sch, interfaces.kicad_sch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]
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2022-07-11 Connect LPDDR5 5VIN to VCC5V_INT, remove redundant resistor on 5V output
    [lpddr4-test-board.kicad_sch, supply.kicad_sch]
2022-07-11 Add 5V led, fix power labels connections
    [lpddr4-test-board.kicad_sch, supply.kicad_sch]
2022-07-13 Fix 1V2 power label in ethernet.sch
    [ethernet.kicad_sch]
2022-07-13 Fix uSC symbol
    [interfaces.kicad_sch]
2022-07-13 Connect DCDCs to sequencer, add test points, change name VCC1V2 to 1V2_SYS
    [lpddr4-test-board.kicad_sch, supply.kicad_sch]
2022-07-13 Update power planes, connect remaining items, clear silks, fix DRC
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2022-07-15 Add 0.6V LDO as an option, fix floating EP on FTDI, clean DRC
    [interfaces.kicad_sch, lpddr4-test-board.kicad_sch, supply.kicad_sch]
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2022-07-15 Fix 1V1 and 1V8 sequencing
    [lpddr4-test-board.kicad_sch, supply.kicad_sch]
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2022-07-18 Layout and routing of load switches. Fixing DRC, improving ppower planes
2022-07-18 Update VDD0V6 to 0V6_DDR, enumerate SYS_EN pullup resistor
    [lpddr4-test-board.kicad_sch, supply.kicad_sch]
2022-07-18 DQS differential pairs renamed to be correctly recognized by KiCad, Created DQ and DQS class, DQ8-11 + DQ_S1 routed and matched with corrected class net parameters
    [fpga-banks.kicad_sch, sodimm.kicad_sch]
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2022-07-20 Make TPS65296 and rail control related components DNP
    [supply.kicad_sch]
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2023-01-31 Added separate symbol with DDR5 testbed footprint and 3D model
    [lpddr4-test-board.kicad_sch, sodimm.kicad_sch]
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2024-09-27 Correct button footprints, correct outline of board
